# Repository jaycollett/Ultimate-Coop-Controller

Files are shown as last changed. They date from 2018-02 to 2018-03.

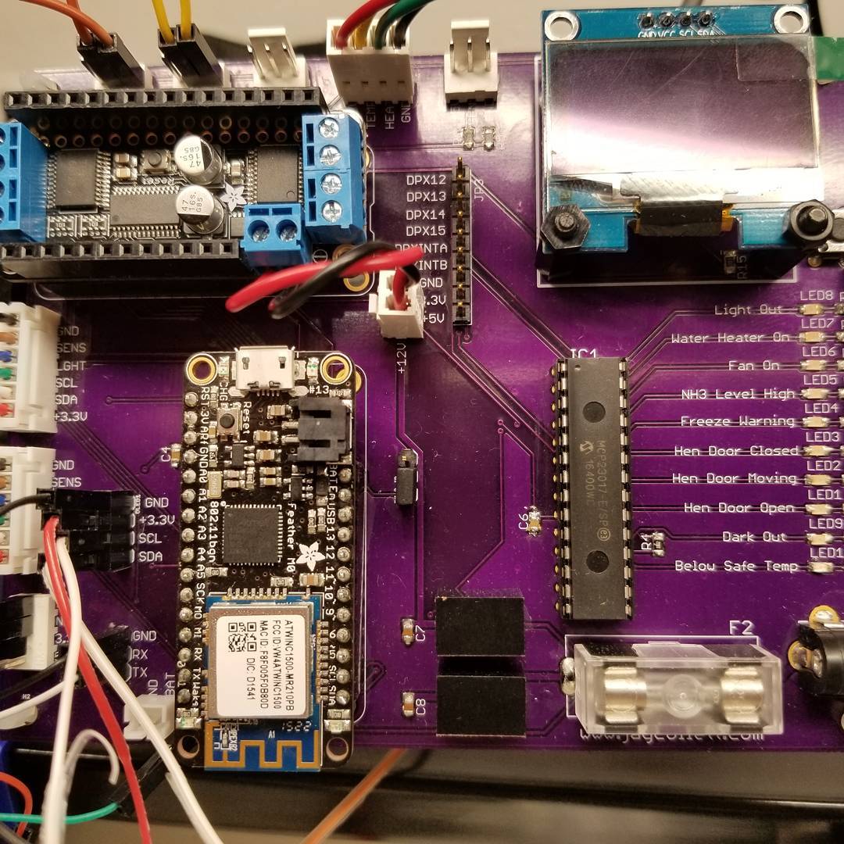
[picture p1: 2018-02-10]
Images/CompletedBoard.jpg

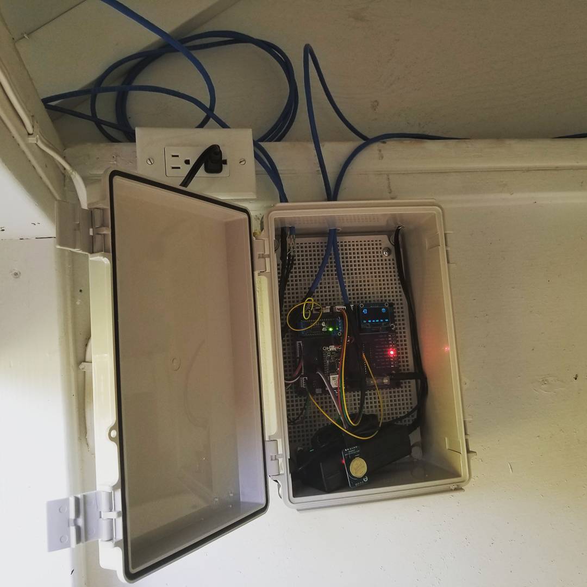
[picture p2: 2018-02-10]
Images/Enclosure.jpg

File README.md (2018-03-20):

# Ultimate-Coop-Controller
Arduino controlled chicken coop sensing and automation

 

More details on this project soon....

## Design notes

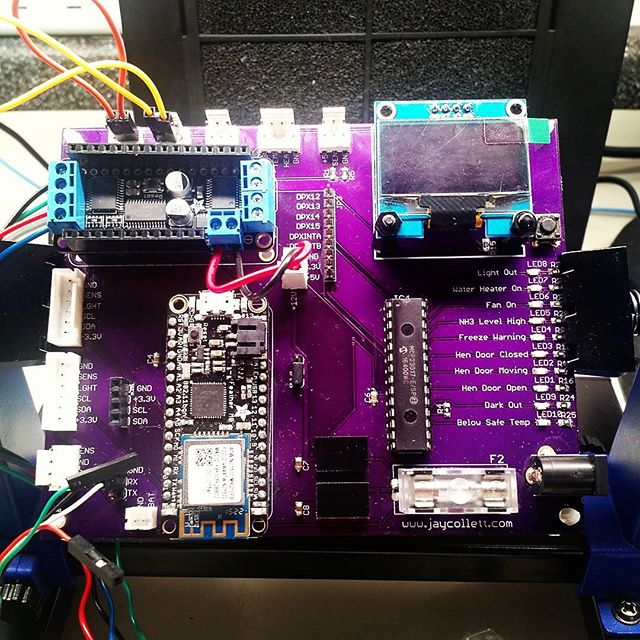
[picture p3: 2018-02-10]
Images/CompletedBoard2.jpg

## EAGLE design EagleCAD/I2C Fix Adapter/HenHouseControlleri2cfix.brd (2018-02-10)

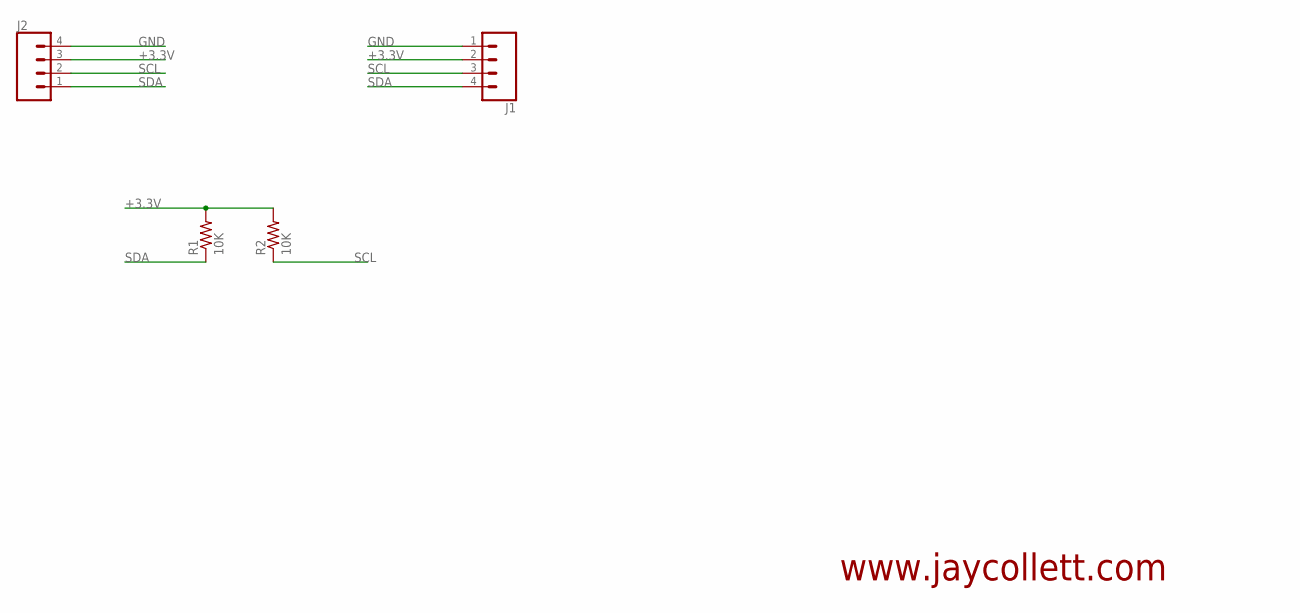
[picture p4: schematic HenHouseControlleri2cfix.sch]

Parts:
J1, J2: CONN_04LONGPADS; 1X04_LONGPADS
R1, R2: 10K; R0805

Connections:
+3.3V: J1.2, J2.3, R1.2, R2.2
GND: J1.1, J2.4
SCL: J1.3, J2.2, R2.1
SDA: J1.4, J2.1, R1.1

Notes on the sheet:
www.jaycollett.com

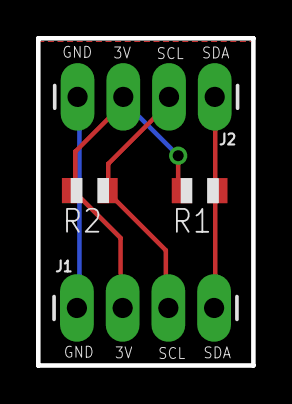
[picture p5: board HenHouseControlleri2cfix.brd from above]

Board: 2 copper layers, 11.9 x 18.2 mm, 4 parts (0 on the bottom side), 4 nets.

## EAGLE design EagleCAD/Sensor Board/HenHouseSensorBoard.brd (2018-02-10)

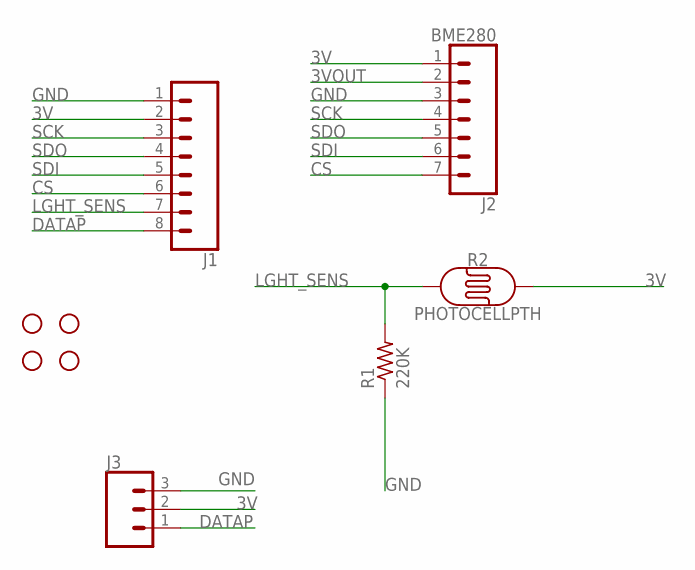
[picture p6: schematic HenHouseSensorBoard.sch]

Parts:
H1, H2, H3, H4: STAND-OFF
J1: CONN_08LONGPADS; 1X08_LONGPADS
J2: BME280; 1X07_LONGPADS
J3: CONN_03LONGPADS; 1X03_LONGPADS
R1: 220K; 0207/9
R2: PHOTOCELLPTH; PHOTOCELL

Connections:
3V: J1.2, J2.1, J3.2, R2.2
3VOUT: J2.2
CS: J1.6, J2.7
DATAP: J1.8, J3.1
GND: J1.1, J2.3, J3.3, R1.1
LGHT_SENS: J1.7, R1.2, R2.1
SCK: J1.3, J2.4
SDI: J1.5, J2.6
SDO: J1.4, J2.5

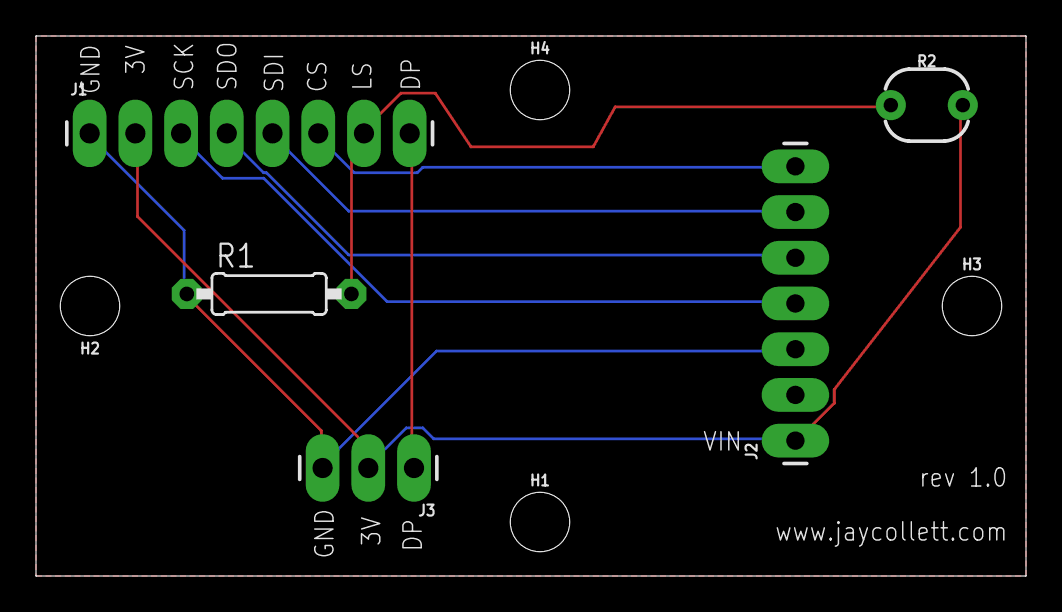
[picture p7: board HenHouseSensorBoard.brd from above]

Board: 2 copper layers, 55.0 x 30.0 mm, 9 parts (0 on the bottom side), 8 nets.

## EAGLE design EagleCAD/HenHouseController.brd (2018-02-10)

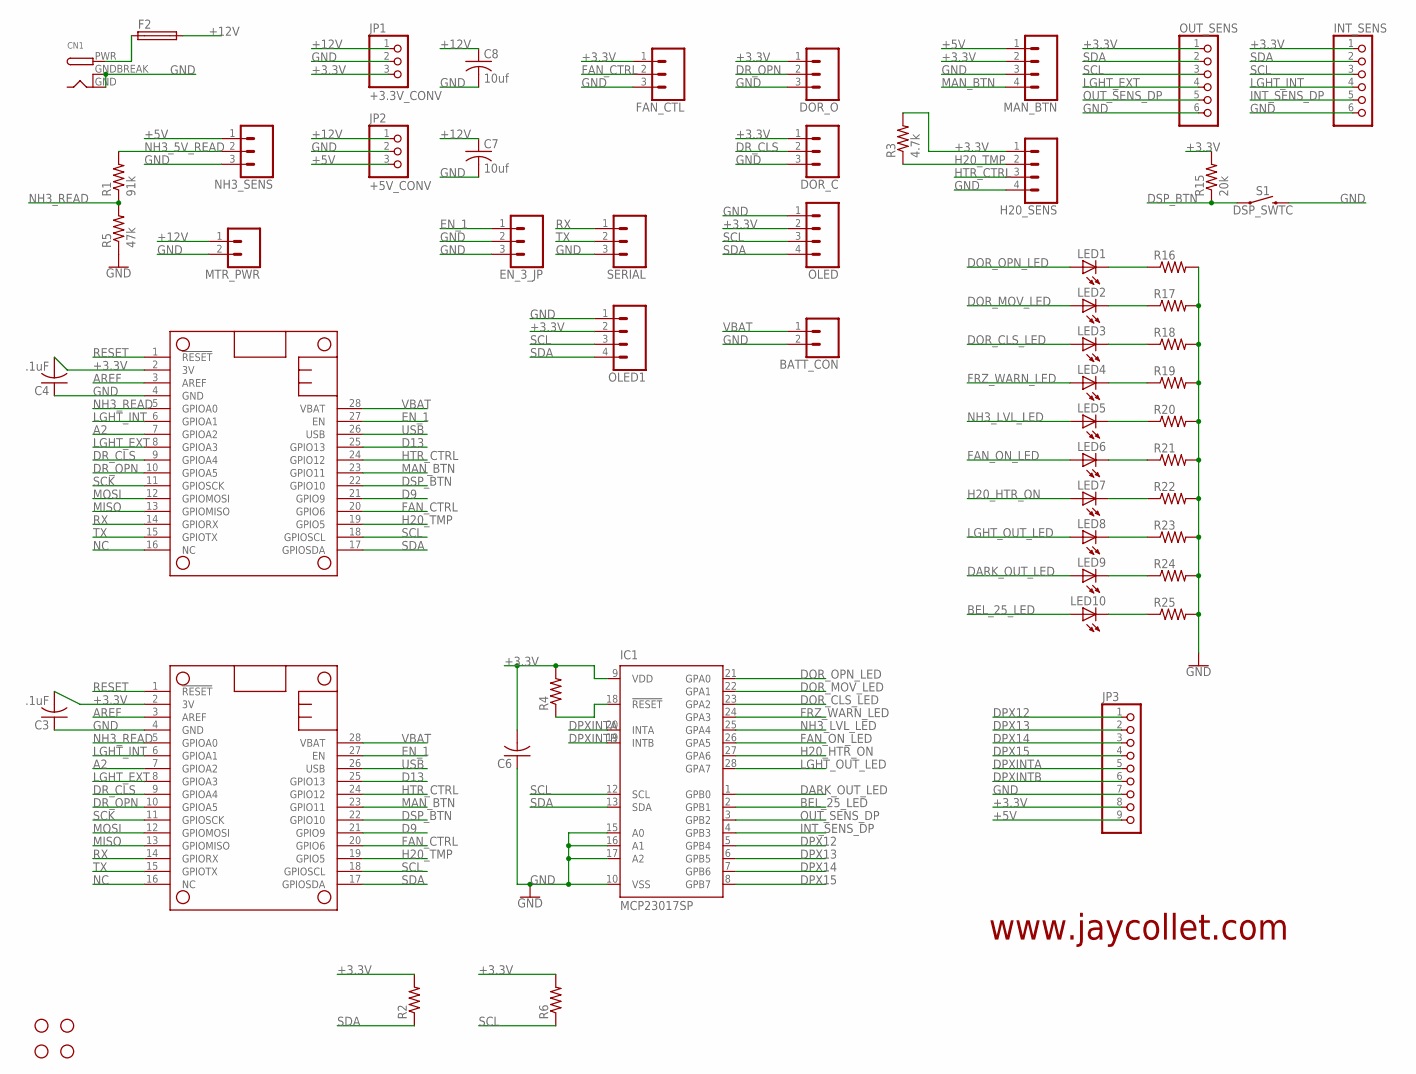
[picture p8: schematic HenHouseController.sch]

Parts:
BATT_CON: CONN_02; 1X02
C3, C4: .1uF; C0805
C6: C-USC0805; C0805
C7, C8: 10uf; C0805
CN1: DCBARRELPTH; DCJACK_2MM_PTH
DOR_C: CONN_03; 1X03
DOR_O: CONN_03; 1X03
EN_3_JP: CONN_03; 1X03
F2: SH25
FAN_CTL: CONN_03; 1X03
FEATHER_1, FEATHER_2: FEATHERWING_NODIM; FEATHERWING_DIM
H1, H2, H3, H4: STAND-OFF
H20_SENS: CONN_04; 1X04
IC1: MCP23017SP; DIL28-3
INT_SENS: PINHD-1X6; 1X06
JP1: +3.3V_CONV; 1X03
JP2: +5V_CONV; 1X03
JP3: PINHD-1X9; 1X09-BIG
LED1, LED2, LED3, LED4, LED5, LED6, LED7, LED8, LED9, LED10: LEDCHIPLED_0805; CHIPLED_0805
MAN_BTN: CONN_04; 1X04
MTR_PWR: CONN_02; 1X02
NH3_SENS: CONN_03; 1X03
OLED, OLED1: CONN_04; 1X04
OUT_SENS: PINHD-1X6; 1X06
R1: 91k; R0805
R2, R6: R-US_M0805; M0805
R3: 4.7k; R0805
R4, R16, R17, R18, R19, R20, R21, R22, R23, R24, R25: R-US_R0805; R0805
R5: 47k; R0805
R15: 20k; M0805
S1: DSP_SWTC; TACTILE_SWITCH_PTH_6.0MM
SERIAL: CONN_03; 1X03

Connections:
+3.3V: C3.2, C4.2, C6.2, DOR_C.1, DOR_O.1, FAN_CTL.1, FEATHER_1.2 (3V), FEATHER_2.2 (3V), H20_SENS.1, IC1.9 (VDD), INT_SENS.1, JP1.3, JP3.8, MAN_BTN.2, OLED.2, OLED1.2, OUT_SENS.1, R2.2, R3.2, R4.2, R6.2, R15.2
+5V: JP2.3, JP3.9, MAN_BTN.1, NH3_SENS.1
+12V: C7.1, C8.1, F2.2, JP1.1, JP2.1, MTR_PWR.1
A2: FEATHER_1.7 (GPIOA2), FEATHER_2.7 (GPIOA2)
AREF: FEATHER_1.3 (AREF), FEATHER_2.3 (AREF)
BEL_25_LED: IC1.2 (GPB1), LED10.A
D9: FEATHER_1.21 (GPIO9), FEATHER_2.21 (GPIO9)
D13: FEATHER_1.25 (GPIO13), FEATHER_2.25 (GPIO13)
DARK_OUT_LED: IC1.1 (GPB0), LED9.A
DOR_CLS_LED: IC1.23 (GPA2), LED3.A
DOR_MOV_LED: IC1.22 (GPA1), LED2.A
DOR_OPN_LED: IC1.21 (GPA0), LED1.A
DPX12: IC1.5 (GPB4), JP3.1
DPX13: IC1.6 (GPB5), JP3.2
DPX14: IC1.7 (GPB6), JP3.3
DPX15: IC1.8 (GPB7), JP3.4
DPXINTA: IC1.20 (INTA), JP3.5
DPXINTB: IC1.19 (INTB), JP3.6
DR_CLS: DOR_C.2, FEATHER_1.9 (GPIOA4), FEATHER_2.9 (GPIOA4)
DR_OPN: DOR_O.2, FEATHER_1.10 (GPIOA5), FEATHER_2.10 (GPIOA5)
DSP_BTN: FEATHER_1.22 (GPIO10), FEATHER_2.22 (GPIO10), R15.1, S1.1
EN_1: EN_3_JP.1, FEATHER_1.27 (EN), FEATHER_2.27 (EN)
FAN_CTRL: FAN_CTL.2, FEATHER_1.20 (GPIO6), FEATHER_2.20 (GPIO6)
FAN_ON_LED: IC1.26 (GPA5), LED6.A
FRZ_WARN_LED: IC1.24 (GPA3), LED4.A
GND: BATT_CON.2, C3.1, C4.1, C6.1, C7.2, C8.2, CN1.GND, CN1.GNDBREAK, DOR_C.3, DOR_O.3, EN_3_JP.2, EN_3_JP.3, FAN_CTL.3, FEATHER_1.4 (GND), FEATHER_2.4 (GND), H20_SENS.4, IC1.10 (VSS), IC1.15 (A0), IC1.16 (A1), IC1.17 (A2), INT_SENS.6, JP1.2, JP2.2, JP3.7, MAN_BTN.3, MTR_PWR.2, NH3_SENS.3, OLED.1, OLED1.1, OUT_SENS.6, R5.1, R16.2, R17.2, R18.2, R19.2, R20.2, R21.2, R22.2, R23.2, R24.2, R25.2, S1.3 (2), SERIAL.3
H20_HTR_ON: IC1.27 (GPA6), LED7.A
H20_TMP: FEATHER_1.19 (GPIO5), FEATHER_2.19 (GPIO5), H20_SENS.2, R3.1
HTR_CTRL: FEATHER_1.24 (GPIO12), FEATHER_2.24 (GPIO12), H20_SENS.3
INT_SENS_DP: IC1.4 (GPB3), INT_SENS.5
LGHT_EXT: FEATHER_1.8 (GPIOA3), FEATHER_2.8 (GPIOA3), OUT_SENS.4
LGHT_INT: FEATHER_1.6 (GPIOA1), FEATHER_2.6 (GPIOA1), INT_SENS.4
LGHT_OUT_LED: IC1.28 (GPA7), LED8.A
MAN_BTN: FEATHER_1.23 (GPIO11), FEATHER_2.23 (GPIO11), MAN_BTN.4
MISO: FEATHER_1.13 (GPIOMISO), FEATHER_2.13 (GPIOMISO)
MOSI: FEATHER_1.12 (GPIOMOSI), FEATHER_2.12 (GPIOMOSI)
unnamed: CN1.PWR, F2.1
unnamed: IC1.18 (!RESET), R4.1
unnamed: LED1.C, R16.1
unnamed: LED2.C, R17.1
unnamed: LED3.C, R18.1
unnamed: LED4.C, R19.1
unnamed: LED5.C, R20.1
unnamed: LED6.C, R21.1
unnamed: LED7.C, R22.1
unnamed: LED8.C, R23.1
unnamed: LED9.C, R24.1
unnamed: LED10.C, R25.1
NC: FEATHER_1.16 (NC), FEATHER_2.16 (NC)
NH3_5V_READ: NH3_SENS.2, R1.2
NH3_LVL_LED: IC1.25 (GPA4), LED5.A
NH3_READ: FEATHER_1.5 (GPIOA0), FEATHER_2.5 (GPIOA0), R1.1, R5.2
OUT_SENS_DP: IC1.3 (GPB2), OUT_SENS.5
RESET: FEATHER_1.1 (!RESET), FEATHER_2.1 (!RESET)
RX: FEATHER_1.14 (GPIORX), FEATHER_2.14 (GPIORX), SERIAL.1
SCK: FEATHER_1.11 (GPIOSCK), FEATHER_2.11 (GPIOSCK)
SCL: FEATHER_1.18 (GPIOSCL), FEATHER_2.18 (GPIOSCL), IC1.12 (SCL), INT_SENS.3, OLED.3, OLED1.3, OUT_SENS.3, R6.1
SDA: FEATHER_1.17 (GPIOSDA), FEATHER_2.17 (GPIOSDA), IC1.13 (SDA), INT_SENS.2, OLED.4, OLED1.4, OUT_SENS.2, R2.1
TX: FEATHER_1.15 (GPIOTX), FEATHER_2.15 (GPIOTX), SERIAL.2
USB: FEATHER_1.26 (USB), FEATHER_2.26 (USB)
VBAT: BATT_CON.1, FEATHER_1.28 (VBAT), FEATHER_2.28 (VBAT)

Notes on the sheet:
www.jaycollet.com

Board: 2 copper layers, 59 parts (0 on the bottom side), 61 nets, no tracks yet.

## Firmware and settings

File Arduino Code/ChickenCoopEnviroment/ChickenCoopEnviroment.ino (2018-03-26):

/********************************************************************************
  Chicken Coop Enviroment Monitor and Controller
  Written by: Jay Collett jay.collett AT gmail.com
  Description: This sketch is for an Adafruit Feather M0 WiFi (WINC1500) and
               is designed to monitor enviromental sensors both inside and
               outside a chicken hen house. All sensor data is sent every
               xx minutes to Adafruit.IO for analyssis. The system leverages
               a featherwing motor control and NEMA 15 motor to control the
               hen house door as well as relays for water heater and fan
               controls. This sketch assumes you are using the custom PCB
               board and pinout.
  Sketch includes unmodified code libraries from the following awesome sources:
      Adafruit.com  https://www.adafruit.com
      sfrwmaker     https://github.com/sfrwmaker/sunMoon
      olikraus      https://github.com/olikraus/u8g2
      jchristensen  https://github.com/JChristensen/Timezone


  This work (excluding external modules/libraries) is licensed under CC BY-SA 4.0

 *********************************************************************************/

// Include all the required libraries
#include "config.h"
#include <Wire.h>
#include <SPI.h>
#include <Adafruit_Sensor.h>
#include <Adafruit_BME280.h>
#include <OneWire.h>
#include <Adafruit_MotorShield.h>
#include "utility/Adafruit_MS_PWMServoDriver.h"
#include <Adafruit_MCP23017.h>
#include <U8g2lib.h>        //https://github.com/olikraus/u8g2
#include <Time.h>
#include <TimeLib.h>
#include <RTClib.h>         //https://github.com/adafruit/RTClib
#include <Timezone.h>       //https://github.com/JChristensen/Timezone
#include <sunMoon.h>        //https://github.com/sfrwmaker/sunMoon

// Define firmware version
#define FIRMWARE_VERSION "0.46"

#define DEBUG

// Setup our debug printing
#ifdef DEBUG
#define debug(x)     Serial1.print(x)
#define debugln(x)   Serial1.println(x)
#else
#define debug(x)     // define empty, so macro does nothing
#define debugln(x)
#endif

// Define pins for SPI (hardware SPI pins) and whatnot
#define LIGHT_PIN_INSIDE A1
#define LIGHT_PIN_OUTSIDE A3
#define WATER_TEMP_PIN 5
#define WATER_HEATER_CTRL_PIN 12
#define DOOR_CLOSED_PIN A4
#define DOOR_OPENED_PIN A5
#define MANUAL_DOOR_CTRL 11
#define NH3_GAS_PIN A0
#define FAN_CTRL_PIN 6

// Define some other compiler time statics
#define SEALEVELPRESSURE_HPA (1013.25)
#define WATER_HEATER_ON_TEMP 40.0
#define WATER_HEATER_OFF_TEMP 45.0
#define AMBIENT_LUX_DARK 11
#define AMBIENT_LUX_LIGHT 40
#define NH3_BURN_IN_MILLIS 86400000
#define NH3_ALARM_LEVEL 180
#define MIN_OUTSIDE_TEMP 20.0

// Define the pins for our 23017 pin expander (used for debug leds)
#define DOOR_OPEN_LED 0
#define DOOR_MOVING_LED 1
#define DOOR_CLOSED_LED 2
#define FREEZE_WARN_LED 3
#define NH3_WARN_LED 4
#define FAN_ON_LED 5
#define H20_HEAT_LED 6
#define LIGHT_OUT_LED 7
#define DARK_OUT_LED 8
#define BELOW_25_LED 9

// Define our long and lat for use in calc of sunrise/sunset
#define LATITUDE  38.037109
#define LONGITUDE  -84.576166

// Define some images for the display (XBM images; monochrome 1-bit bitmaps)
#define sun_image_width 20
#define sun_image_height 20
static const unsigned char sun_image_bits[] = {
  0x00, 0x06, 0x00, 0x00, 0x06, 0x00, 0x08, 0x06, 0x01, 0x1c, 0x80, 0x01,
  0x18, 0x80, 0x01, 0x80, 0x1f, 0x00, 0xc0, 0x30, 0x00, 0x60, 0x60, 0x00,
  0x20, 0x40, 0x00, 0x27, 0x40, 0x0e, 0x27, 0x40, 0x0e, 0x20, 0x40, 0x00,
  0x60, 0x60, 0x00, 0xc0, 0x30, 0x00, 0x80, 0x1f, 0x00, 0x18, 0x80, 0x01,
  0x1c, 0x80, 0x03, 0x00, 0x06, 0x01, 0x00, 0x06, 0x00, 0x00, 0x06, 0x00
};
#define moon_image_width 20
#define moon_image_height 20
static const unsigned char moon_image_bits[] = {
  0x40, 0x00, 0x00, 0x10, 0x00, 0x00, 0x30, 0x00, 0x00, 0x00, 0x00, 0x00,
  0x0e, 0x00, 0x00, 0x30, 0x00, 0x00, 0x02, 0x00, 0x00, 0x7d, 0x00, 0x00,
  0x01, 0x00, 0x00, 0x52, 0x00, 0x00, 0x56, 0x00, 0x00, 0xa0, 0x00, 0x00,
  0xaf, 0x00, 0x00, 0x40, 0x07, 0x0c, 0x4a, 0x0c, 0x00, 0x94, 0xf3, 0x01,
  0x10, 0x06, 0x03, 0x20, 0xf8, 0x00, 0xe0, 0x00, 0x00, 0x00, 0x1b, 0x00
};
#define fan_image_width 20
#define fan_image_height 20
static const unsigned char fan_image_bits[] = {
  0x00, 0x00, 0x00, 0x00, 0x0f, 0x00, 0xe0, 0x1f, 0x00, 0x70, 0x80, 0x01,
  0x38, 0x80, 0x01, 0x1c, 0x80, 0x01, 0x0c, 0x00, 0x03, 0x04, 0x00, 0x02,
  0x06, 0x00, 0x06, 0x06, 0x00, 0x06, 0x06, 0x00, 0x06, 0x06, 0x00, 0x06,
  0x04, 0x00, 0x02, 0x1c, 0x00, 0x03, 0x1c, 0x80, 0x01, 0x1c, 0xc0, 0x01,
  0x00, 0xe0, 0x00, 0xc0, 0x3f, 0x00, 0x00, 0x0f, 0x00, 0x00, 0x00, 0x00
};
#define heater_image_width 20
#define heater_image_height 20
static const unsigned char heater_image_bits[] = {
  0x00, 0x00, 0x00, 0x00, 0x00, 0x00, 0x00, 0x00, 0x00, 0x00, 0x00, 0x00,
  0x00, 0x06, 0x00, 0x20, 0x4f, 0x00, 0xf0, 0xff, 0x00, 0xf0, 0xff, 0x00,
  0xf8, 0xff, 0x01, 0xf8, 0xff, 0x01, 0xf8, 0xf9, 0x01, 0xf8, 0xf0, 0x01,
  0x78, 0xe0, 0x01, 0x70, 0xe0, 0x00, 0x70, 0x70, 0x00, 0xc0, 0x3f, 0x00,
  0x80, 0x1f, 0x00, 0x00, 0x00, 0x00, 0x00, 0x00, 0x00, 0x00, 0x00, 0x00
};
#define door_open_image_width 20
#define door_open_image_height 20
static const unsigned char door_open_image_bits[] = {
  0x00, 0x00, 0x00, 0xfe, 0x1f, 0x00, 0x06, 0x18, 0x00, 0x02, 0x10, 0x00,
  0x02, 0x10, 0x00, 0x02, 0x10, 0x00, 0x02, 0xc0, 0x00, 0x02, 0xc0, 0x01,
  0x02, 0x80, 0x03, 0x82, 0xff, 0x07, 0x82, 0xff, 0x07, 0x02, 0x80, 0x03,
  0x02, 0xc0, 0x01, 0x02, 0xc0, 0x00, 0x02, 0x10, 0x00, 0x02, 0x10, 0x00,
  0x02, 0x10, 0x00, 0xfe, 0x1f, 0x00, 0xfe, 0x1f, 0x00, 0x00, 0x00, 0x00
};
#define door_closed_image_width 20
#define door_closed_image_height 20
static const unsigned char door_closed_image_bits[] = {
  0x00, 0x00, 0x00, 0x80, 0xff, 0x07, 0x80, 0x01, 0x06, 0x80, 0x00, 0x06,
  0x80, 0x00, 0x06, 0x80, 0x00, 0x06, 0x30, 0x00, 0x06, 0x38, 0x00, 0x06,
  0x1c, 0x00, 0x06, 0xfe, 0x1f, 0x06, 0xfe, 0x1f, 0x06, 0x1c, 0x00, 0x06,
  0x38, 0x00, 0x06, 0x30, 0x00, 0x06, 0x80, 0x00, 0x06, 0x80, 0x00, 0x06,
  0x80, 0x00, 0x06, 0x80, 0xff, 0x07, 0x80, 0xff, 0x07, 0x00, 0x00, 0x00
};

// Setup some consts and other variables needed through the scope of the sketch
const byte waterTempSensorAddr[8] = {0x28, 0xFF, 0x74, 0x3F, 0xA4, 0x16, 0x5, 0xF9};
const long logInterval = 600000;                // interval to update Adafruit IO data (10 mins)
const long tempCheckInterval = 300000;          // internal to check water temp (5 mins)
const long doorCheckInterval = 30000;           // internal to check door status and action (5 mins)
const int doorCloseDelay = 1800;                // (1800 seconds = 30 mins) interval to wait before closing door (allows hens to get in at dark or fully light out)
const long nh3CheckInterval = 600000;           // internal to check door status and action (10 mins)
const long fanCheckInterval = 650000;           // interval to check fan status and action (15 mins)
const long nh3BurnInMillis = 14400000;          // 4 hours before we should be able to get "valid" readings from the sensor
const long doorTransitionTimeout = 55000;       // time in ms to allow door to transition before just shutting down (safety measure)
unsigned long currentMillis;                    // store LOT mcu has been running
unsigned long previousLogMillis = 0;            // store last time we logged data
unsigned long previousTempCheckMillis = 0;      // store last time we checked water temp
unsigned long previousDoorCheckMillis = 0;      // store last time we checked door status
unsigned long previousNH3Millis = 0;            // store last time we logged data
unsigned long previousFanCheckMillis = 0;       // store last time we checked the fan status
unsigned long doorTransistionStart = 0;         // store time we started the door transition

int waterTemp = 99;
int insideTemp = 999;
int outsideTemp = 999;
float currentWaterTemp = 0.0;     // stores the temp for our checks on water temp to control heater
unsigned int inetAttempts = 0;
int updateDisplayDelayCount = 0;  // count display loops
int updateDisplayLoop = 20;      // number of loops to wait till we update OLED display

bool waterHeaterOn = false;       // bool to hold status of water heater
bool doorOpen = false;            // bool to hold status of door
bool nh3BurnInComplete = false;   // hold status of burn-in for nh3 sensor
bool fanOn = false;               // bool to hold status of hen house fan
bool nh3Alarm = false;            // based on nh3 sensor data, is the level too high
bool freezeAlarm = false;         // based on outside temp, set freeze alarm
bool pubRetValue = false;         // bool to hold results of mqtt publish commands


// Setup our RTC object
RTC_DS3231 rtcObj;

// Setup our timezone object
//US Eastern Time Zone (New York, Detroit)
TimeChangeRule usEDT = {"EDT", Second, Sun, Mar, 2, -240};    //Daylight time = UTC - 4 hours
TimeChangeRule usEST = {"EST", First, Sun, Nov, 2, -300};     //Standard time = UTC - 5 hours
Timezone usEastern(usEDT, usEST);
TimeChangeRule *tcr;        //pointer to the time change rule, use to get TZ abbrev

// Setup sunMoon library object
sunMoon sunMoonObj;

// Setup our 23017 pin expander (uses i2c)
Adafruit_MCP23017 pinExpander;

// Setup a BME280 instance for each of our AdaFruit breakout boards using I2C
Adafruit_BME280 bmeInside;  //addr 0x77
Adafruit_BME280 bmeOutside; //addr 0x76 sdo to gnd

// Water Sensor Address (manual based on each sensor)
OneWire  ds(WATER_TEMP_PIN);  // on pin WATER_TEMP_PIN (a 4.7K resistor is necessary)

// Setting up motorshield objects using i2c
Adafruit_MotorShield AFMS = Adafruit_MotorShield();
Adafruit_StepperMotor *myMotor = AFMS.getStepper(200, 2); // 200 steps per rev on port #2

// Setup our onboard OLED display
U8G2_SH1106_128X64_VCOMH0_F_HW_I2C onBoardDisplay(U8G2_R0, /* clock=*/ SCL, /* data=*/ SDA, /* reset=*/ U8X8_PIN_NONE);

void writeToonBoardDisplay(String textToWrite) {
  int strLen = textToWrite.length() + 1; // get length plus 1 for null terminator
  char charToWrite[strLen];
  textToWrite.toCharArray(charToWrite, strLen);

  onBoardDisplay.clearBuffer();          // clear the internal memory
  onBoardDisplay.setFont(u8g2_font_6x10_mr);
  onBoardDisplay.drawStr(10, 40, charToWrite); // write something to the internal memory
  onBoardDisplay.sendBuffer();          // transfer internal memory to the display
  //!*!*!*!*!*!*!*!*!*!*!*!*!*!*!*!*!*!*!*!*!*!*!*!*!*!*!*!*!*!*!*!*!*!*!*!*!*!*!*!*!*!*!*!*!*
}

// @@@@@@@@@@@@@@@@@@@@@@@@@@@@@@@@@@@@@@@@@@@@@@@@@@@@@@@@@@@@@@@@@@@@@@@@@@@@@@@@@@@@@@@@@@@@@@@@@@@@@@@@@@@@@@@@@@@@@@@@
//                                                        SETUP BLOCK
// @@@@@@@@@@@@@@@@@@@@@@@@@@@@@@@@@@@@@@@@@@@@@@@@@@@@@@@@@@@@@@@@@@@@@@@@@@@@@@@@@@@@@@@@@@@@@@@@@@@@@@@@@@@@@@@@@@@@@@@@
void setup() {

  // starting onboard oled display
  onBoardDisplay.begin();

  // Setup the hw serial for the feather, used for debug...
#ifdef DEBUG
  Serial1.begin(9600);
#endif


  debugln("Showing boot screen...");
  // show boot screen and pause a bit
  // !*!*!*!*!*!*!*!*!*!*!*!*!*!*!*!*!*!*!*!*!*!*!*!*!*!*!*!*!*!*!*!*!*!*!*!*!*!*!*!*!*!*!*!*!*
  onBoardDisplay.clearBuffer();                         // clear the internal memory
  onBoardDisplay.setFont(u8g2_font_6x10_mr);
  onBoardDisplay.drawStr(0, 10, "Ultimate Coop");       // write something to the internal memory
  onBoardDisplay.drawStr(0, 20, "Controller");          // write something to the internal memory
  onBoardDisplay.drawStr(10, 40, "www.jaycollett.com"); // write something to the internal memory
  onBoardDisplay.drawStr(104, 60, FIRMWARE_VERSION);    // write something to the internal memory
  onBoardDisplay.sendBuffer();                          // transfer internal memory to the display
  delay(5000);
  //!*!*!*!*!*!*!*!*!*!*!*!*!*!*!*!*!*!*!*!*!*!*!*!*!*!*!*!*!*!*!*!*!*!*!*!*!*!*!*!*!*!*!*!*!*

  writeToonBoardDisplay("booting...");

  // Set up our pin modes
  pinMode(LIGHT_PIN_INSIDE, INPUT);
  pinMode(LIGHT_PIN_OUTSIDE, INPUT);
  pinMode(WATER_HEATER_CTRL_PIN, OUTPUT);
  pinMode(DOOR_CLOSED_PIN, INPUT_PULLUP);
  pinMode(DOOR_OPENED_PIN, INPUT_PULLUP);
  pinMode(MANUAL_DOOR_CTRL, INPUT_PULLUP);
  pinMode(NH3_GAS_PIN, INPUT);

  // setup pin expander pin modes
  pinExpander.begin();
  pinExpander.pinMode(DOOR_OPEN_LED, OUTPUT);
  pinExpander.pinMode(DOOR_MOVING_LED, OUTPUT);
  pinExpander.pinMode(DOOR_CLOSED_LED, OUTPUT);
  pinExpander.pinMode(FREEZE_WARN_LED, OUTPUT);
  pinExpander.pinMode(NH3_WARN_LED, OUTPUT);
  pinExpander.pinMode(FAN_ON_LED, OUTPUT);
  pinExpander.pinMode(H20_HEAT_LED, OUTPUT);
  pinExpander.pinMode(LIGHT_OUT_LED, OUTPUT);
  pinExpander.pinMode(DARK_OUT_LED, OUTPUT);
  pinExpander.pinMode(BELOW_25_LED, OUTPUT);


  // Set default output pin states
  digitalWrite(WATER_HEATER_CTRL_PIN, LOW);

  // Setup and init our RTC object
  debugln("Setting up RTC object...");
  delay(700);
  writeToonBoardDisplay("setting rtc...");
  rtcObj.begin();

  setSyncProvider(syncProvider);   // the function to get the time from the RTC

#ifdef DEBUG
  if (timeStatus() != timeSet)
    debugln("Unable to sync with the RTC or the time hasn't been set on RTC");
  else
    debugln("RTC has set the system time");
#endif

#ifdef DEBUG
  // display the debug UTC and local time
  Serial1.println("Showing UTC from RTC");
  printTime(now(), "UTC");
  Serial1.println("Showing local time from RTC UTC value");
  // display the debug local time and daylight savings abbrev
  printTime(usEastern.toLocal(now(), &tcr), tcr -> abbrev);
#endif

  writeToonBoardDisplay("finding sensors...");
  delay(700);
  // validate we can communicate with the sensors...
  debugln("Starting bme sensors...");
  bmeInside.begin(0x77);
  bmeOutside.begin(0x76);

  // connect to wifi and mqtt server (this takes care of both, call this in loop as well)
  writeToonBoardDisplay("starting network...");
  Ethernet.init(WIZ_CS);
  delay(1100);

  // start ethernet
  if (Ethernet.begin(mac) == 0)
  {
    writeToonBoardDisplay("dhcp init fail...");
    delay(2000);
    Serial1.println("Failed to configure Ethernet using DHCP");

    Ethernet.begin(mac, ip, dnsServer, gateway, subnet);
    return;
  }

  delay(2500);

  MQTT_connect();

  writeToonBoardDisplay("inet alive...");
  delay(3000);

  // set default status for door, fan, and water heater
  mqttclient.publish("Coop/Inside/WaterHeater", "Off");
  delay(150);
  mqttclient.publish("Coop/Inside/Fan", "Off");
  delay(150);

  // Setup stepper motor control
  AFMS.begin();
  myMotor->setSpeed(90);  // set default RPM for stepper motor

  // Get the status of the hen house door (we don't know if it was open or closed)
  // south pole of magnent is present if low
  if ( (digitalRead(DOOR_CLOSED_PIN) == LOW) && (digitalRead(DOOR_OPENED_PIN) == HIGH)) {
    debugln("Setting inital door state to CLOSED");
    doorOpen = false;
    pinExpander.digitalWrite(DOOR_MOVING_LED, LOW);
    pinExpander.digitalWrite(DOOR_OPEN_LED, LOW);
    pinExpander.digitalWrite(DOOR_CLOSED_LED, HIGH);
    mqttclient.publish("Coop/Inside/Door", "Closed");
  }
  else if ( (digitalRead(DOOR_CLOSED_PIN) == HIGH) && (digitalRead(DOOR_OPENED_PIN) == LOW)) {
    debugln("Setting inital door state to OPEN");
    doorOpen = true;
    pinExpander.digitalWrite(DOOR_MOVING_LED, LOW);
    pinExpander.digitalWrite(DOOR_OPEN_LED, HIGH);
    pinExpander.digitalWrite(DOOR_CLOSED_LED, LOW);
    mqttclient.publish("Coop/Inside/Door", "Open");
  }
  else {
    // well, the door must be stuck inbetween open and close, neither sensor is showing it's position, let's try to close it
    debugln("Couldn't get door status, attempting closeDoor() call..");
    closeDoor();
  }
  writeToonBoardDisplay("finding sensors");
}
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

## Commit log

2018-02-10 Tweaking system reset on hard faults and door errors
    [HenHouseController.brd, HenHouseController.sch, HenHouseControlleri2cfix.brd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]
2018-02-12 fixed some errors in comment spelling
    [ChickenCoopEnviroment.ino]
2018-02-12 fixing up more comments
    [ChickenCoopEnviroment.ino]
2018-02-15 trying new library names in travis file for arduino
2018-02-19 fixin up some mqtt errors
    [ChickenCoopEnviroment.ino]
2018-02-20 trying code to fix publish of door status
    [ChickenCoopEnviroment.ino]
2018-03-26 fixing the client id on mqtt conect that was using server ip
    [ChickenCoopEnviroment.ino]

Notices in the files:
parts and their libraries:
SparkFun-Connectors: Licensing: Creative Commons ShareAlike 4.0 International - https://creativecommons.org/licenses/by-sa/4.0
